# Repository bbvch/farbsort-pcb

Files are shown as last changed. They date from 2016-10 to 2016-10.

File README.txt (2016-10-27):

Eagle design files for Farbsort Cape for Beagle Bone

My work was based on Adafruit's Proto Cape Kit for Beagle Bone. See details below.

Adafruit Proto Cape Kit for Beagle Bone

These are the Eagle CAD files for the Adafruit Proto Cape Kit for Beagle Bone:
  ----> http://www.adafruit.com/products/572

Adafruit invests time and resources providing this open source design, please support Adafruit and open-source hardware by purchasing products from Adafruit!

Add some circuitry to your Beagle Bone with our lovely Proto Cape. If you have a 'Bone you need one of these! This PCB fits neatly on top of a Beagle Bone, without getting in the way of the Ethernet jack, and provides a breakout to both 46 pin headers - with individual numbering to keep them straight. We also threw down some strips to access the 5V and 3V power supplies as well as two SMT breakouts, one for SOIC-8's and one for SOT-23's.

Kit comes with a double-sided FR4 PCB and 3 sticks of header. You'll need to place the header into the Beagle Bone and then solder the Proto Cape PCB in place, but its very easy and should take only 10 minutes max even for beginners

All text above must be included in any redistribution

Designed by Limor Fried/Ladyada and Kevin Townsend for Adafruit Industries.
Creative Commons Attribution/Share-Alike, all text above must be included in any redistribution

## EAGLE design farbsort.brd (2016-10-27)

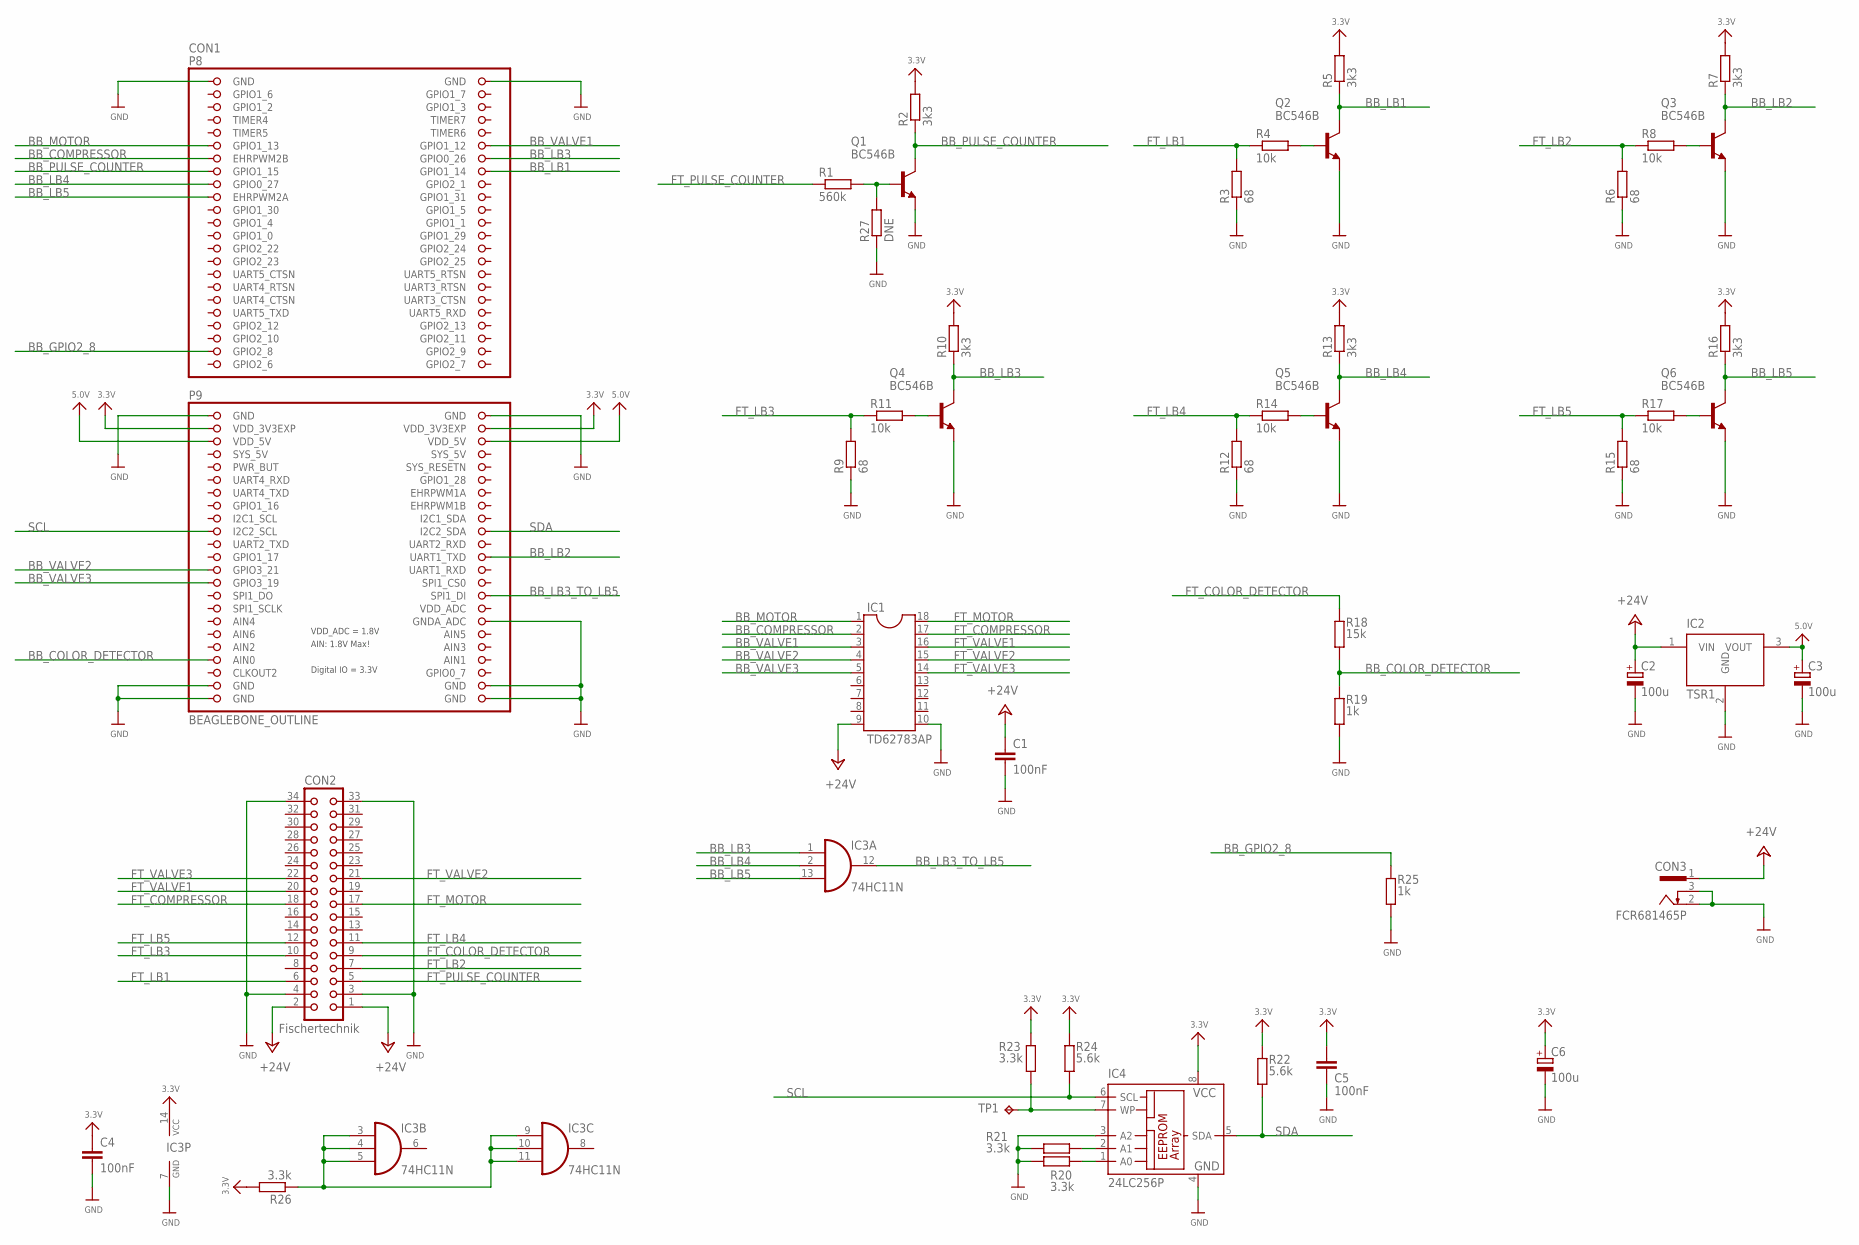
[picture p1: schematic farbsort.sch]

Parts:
C1, C4, C5: 100nF; C025-024X044
C2, C3, C6: 100u; B45181B
CON1: BEAGLEBONE_OUTLINE; BEAGLEBONE_SHIELD
CON2: Fischertechnik; CON34
CON3: FCR681465P; SCD-014-A
IC1: TD62783AP; DIL18
IC2: TSR1
IC3: 74HC11N; DIL14
IC4: 24LC256P; DIL8
Q1, Q2, Q3, Q4, Q5, Q6: BC546B; TO92-EBC
R1: 560k; 0204V
R2, R5, R7, R10, R13, R16: 3k3; 0204V
R3, R6, R9, R12, R15: 68; 0204V
R4, R8, R11, R14, R17: 10k; 0204V
R18: 15k; 0204V
R19, R25: 1k; 0204V
R20, R21, R23, R26: 3.3k; 0204V
R22, R24: 5.6k; 0204V
R27: DNE; 0204V
TP1: TPB1,27; B1,27

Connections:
3.3V: C4.1, C5.1, C6.+, CON1.49 (VDD_3V3EXP), CON1.50 (VDD_3V3EXP), IC3.14 (VCC), IC4.8 (VCC), R2.2, R5.2, R7.2, R10.2, R13.2, R16.2, R22.1, R23.1, R24.1, R26.2
5.0V: C3.+, CON1.51 (VDD_5V), CON1.52 (VDD_5V), IC2.3 (VOUT)
+24V: C1.1, C2.+, CON2.1, CON2.2, CON3.1, IC1.9, IC2.1 (VIN)
BB_COLOR_DETECTOR: CON1.85 (AIN0), R18.2, R19.1
BB_COMPRESSOR: CON1.13 (EHRPWM2B), IC1.2
BB_GPIO2_8: CON1.43 (GPIO2_8), R25.1
BB_LB1: CON1.16 (GPIO1_14), Q2.C, R5.1
BB_LB2: CON1.70 (UART1_TXD), Q3.C, R7.1
BB_LB3: CON1.14 (GPIO0_26), IC3.1 (I0), Q4.C, R10.1
BB_LB3_TO_LB5: CON1.76 (SPI1_DI), IC3.12 (O)
BB_LB4: CON1.17 (GPIO0_27), IC3.2 (I1), Q5.C, R13.1
BB_LB5: CON1.19 (EHRPWM2A), IC3.13 (I2), Q6.C, R16.1
BB_MOTOR: CON1.11 (GPIO1_13), IC1.1
BB_PULSE_COUNTER: CON1.15 (GPIO1_15), Q1.C, R2.1
BB_VALVE1: CON1.12 (GPIO1_12), IC1.3
BB_VALVE2: CON1.71 (GPIO3_21), IC1.4
BB_VALVE3: CON1.73 (GPIO3_19), IC1.5
FT_COLOR_DETECTOR: CON2.9, R18.1
FT_COMPRESSOR: CON2.18, IC1.17
FT_LB1: CON2.6, R3.2, R4.1
FT_LB2: CON2.7, R6.2, R8.1
FT_LB3: CON2.10, R9.2, R11.1
FT_LB4: CON2.11, R12.2, R14.1
FT_LB5: CON2.12, R15.2, R17.1
FT_MOTOR: CON2.17, IC1.18
FT_PULSE_COUNTER: CON2.5, R1.1
FT_VALVE1: CON2.20, IC1.16
FT_VALVE2: CON2.21, IC1.15
FT_VALVE3: CON2.22, IC1.14
GND: C1.2, C2.-, C3.-, C4.2, C5.2, C6.-, CON1.1 (GND), CON1.2 (GND), CON1.47 (GND), CON1.48 (GND), CON1.80 (GNDA_ADC), CON1.89 (GND), CON1.90 (GND), CON1.91 (GND), CON1.92 (GND), CON2.3, CON2.4, CON2.33, CON2.34, CON3.2, CON3.3, IC1.10, IC2.2 (GND), IC3.7 (GND), IC4.3 (A2), IC4.4 (GND), Q1.E, Q2.E, Q3.E, Q4.E, Q5.E, Q6.E, R3.1, R6.1, R9.1, R12.1, R15.1, R19.2, R20.1, R21.1, R25.2, R27.1
unnamed: Q1.B, R1.2, R27.2
unnamed: IC3.3 (I0), IC3.4 (I1), IC3.5 (I2), IC3.9 (I0), IC3.10 (I1), IC3.11 (I2), R26.1
unnamed: Q2.B, R4.2
unnamed: IC4.7 (WP), R23.2, TP1.TP
unnamed: Q3.B, R8.2
unnamed: IC4.2 (A1), R21.2
unnamed: IC4.1 (A0), R20.2
unnamed: Q4.B, R11.2
unnamed: Q5.B, R14.2
unnamed: Q6.B, R17.2
SCL: CON1.65 (I2C2_SCL), IC4.6 (SCL), R24.2
SDA: CON1.66 (I2C2_SDA), IC4.5 (SDA), R22.2
SYS_5V: CON1.53 (SYS_5V), CON1.54 (SYS_5V)
VDD_ADC: CON1.78 (VDD_ADC)

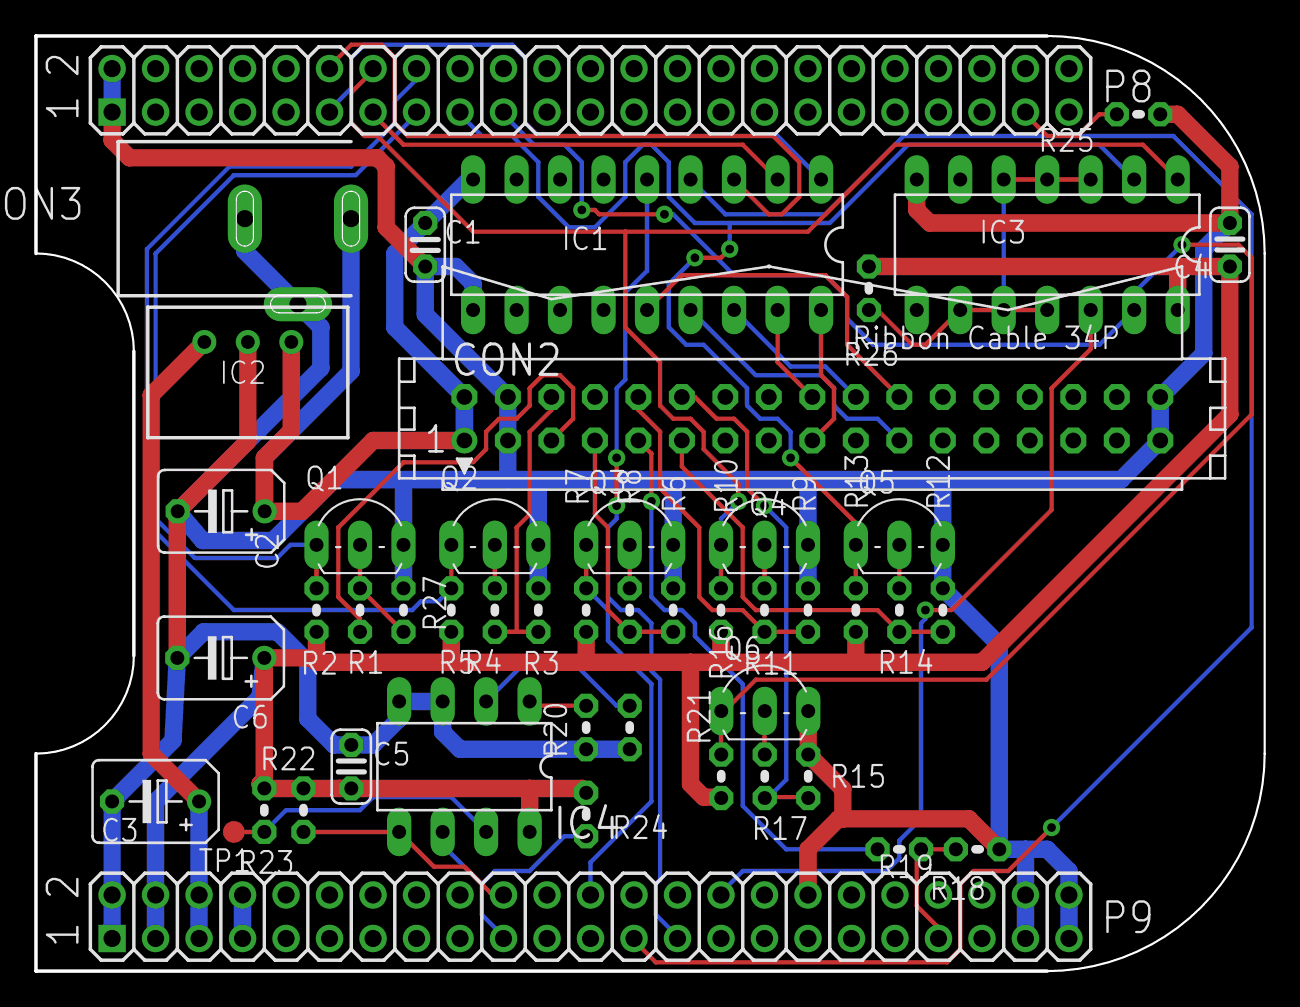
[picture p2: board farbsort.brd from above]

Board: 2 copper layers, 71.8 x 54.6 mm, 47 parts (0 on the bottom side), 43 nets.
